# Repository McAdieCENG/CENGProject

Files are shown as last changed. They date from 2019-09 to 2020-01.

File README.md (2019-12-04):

# CENGProject Greenhouse System

## Table of Contents
1. [Introduction](#Introduction)
2. [Bill of Materials](#Bill-of-Materials)
3. [Time Commitment](#Time-Commitment)
4. [Mechanical Assembly](#Mechanical-Assembly)
5. [PCB/Soldering](#PCBSoldering)
6. [Power Up and Unit Testing](#Power-Up-and-Unit-Testing)
7. [Production Testing](#Production-Testing)

## Introduction
Welcome to the build guide for the BME680 sensor to use in devolpment with a greenhouse system. The scope of this project is to learn and integrate a piece of hardware with the broadcomm development platform. In our case, we will be using a Raspberry Pi 3 B+ as our platform to integrate with the BME680 sensor. All of which can then be used for real world applications such as the stated greenhouse system. Below is an image of a finished version of this project.

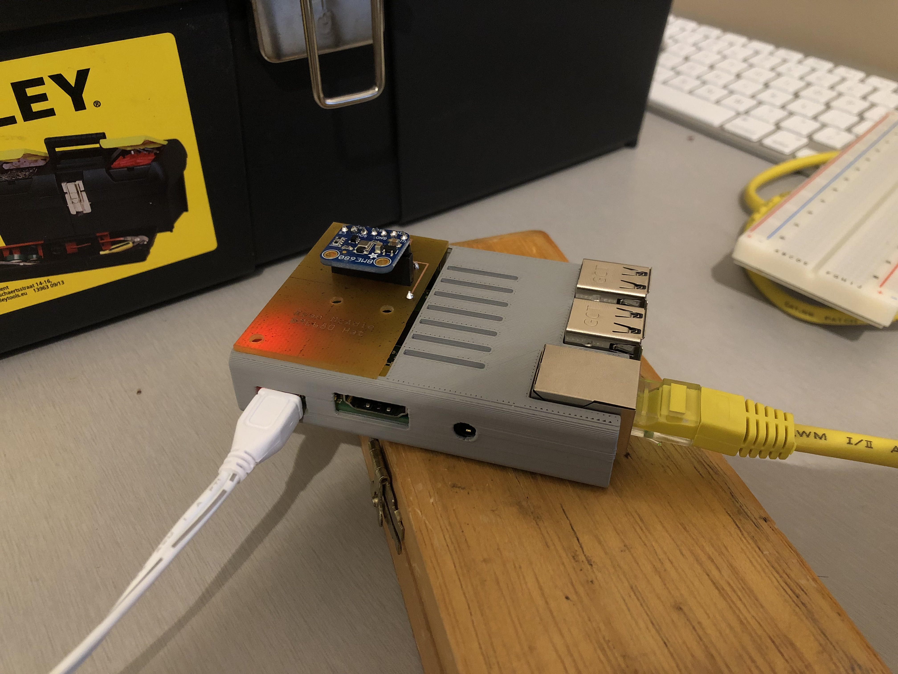
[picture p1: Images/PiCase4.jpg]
Finished Product


## Bill of Materials
**Tools Used:**
- Soldering Iron
- 3D Printer
- PCB Milling Machine
- Wire Cutters/Strippers

**Materials Used:**
- PLA Spool for 3D printer
- PCB Boards
- Small Gage Wire
- Solder

**Other Items Needed/Used**
- Laptop
- Ethernet Cable
- Internet Connection

**Item Budget Sheet: [Click Here for Budget File With Clickable Links](https://github.com/McAdieCENG/CENGProject/blob/master/Documentation/Budget%20Files/Budget.xlsx)**
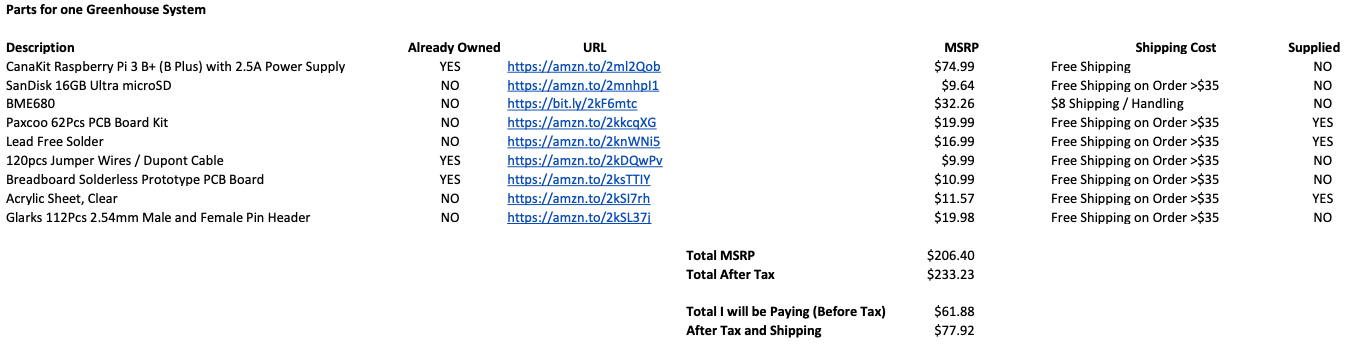
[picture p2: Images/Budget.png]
Budget


These products are what I used to complete this project, some or all products may not be required if you already have access to them or wish to use a supliment product inplace of the ones I have used. **Keep in mind, as a student I was able to aquire my PCB board and 3D printed case for FREE as part of my tuition. These items will need to be aquired by a 3rd party supplier or manufacturer to complete this build and will most likly cost a small fee.**

## Time Commitment
This project ran its course over an entire school semester (4 months, ~15 weeks). The average time per week spend working on this project including class time, was around ~5 hours. With an average understanding of computers and hardware assembly, I would estimate that the time to potentially complete this project would be around 7-8 hours. That being said, I have made this estimate based on the fact that you should have all or most of the required parts at the time of production. Please be advisded of shipping times when ordering parts or materials, some products may be coming from over seas and require longer time to arrive. A full schedule break down for my time used over the school semester can be found [here.](https://github.com/McAdieCENG/CENGProject/blob/master/Documentation/Schedule%20Files/CENG317Schedule-pages-deleted.pdf)

## Mechanical Assembly
**Raspberry Pi Setup:**  
When it comes to setting up your Raspberry Pi for this build there are a few quick tutorials online that can help you through this portion of the build. The first tutorial can be found at this [link here.](https://projects.raspberrypi.org/en/projects/raspberry-pi-setting-up) After completing the initial setup of the Pi following the first link, you can use [this link](https://www.raspberrypi.org/documentation/remote-access/vnc/README.md) to set up the Pi to accept a remote desktop connection through a program called VNC viewer. It may also be a good idea to enable I2C, you can follow this [link here](https://learn.adafruit.com/adafruits-raspberry-pi-lesson-4-gpio-setup/configuring-i2c) to get that done. Lastly, we need to install the appropriate libraries for the BME680 to work properly, just follow [this](https://github.com/adafruit/Adafruit_CircuitPython_BME680) Adafruit GitHub tutorial to get those installed. After completing these few tutorials you can power down your Raspberry Pi for now as we do not need it quite yet.

**Custom Case:**  
If you'd like to 3D print the same case I used in this project the files can be found [here.](https://github.com/McAdieCENG/CENGProject/tree/master/Documentation/Case%20Files) You can either use the program [OpenSCAD](https://www.openscad.org/) to edit the `.scad` file to your liking OR use the file `Case.stl` as is to print the same case I used for the build.

**Breadboard Setup: (This step is optional, can be used to verify the integrity of the sensor)**  
1. Connect wires to the sensor and the development platform like shown below:
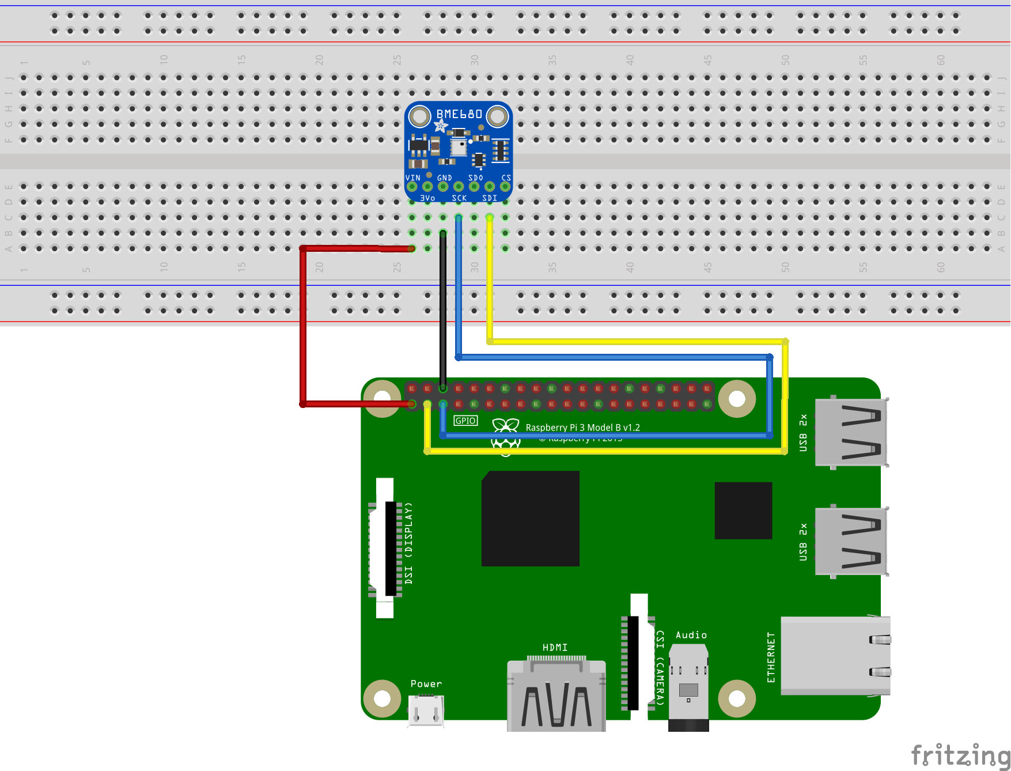
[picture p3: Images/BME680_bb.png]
Breadboard

2. Download the test program from [here](https://github.com/McAdieCENG/CENGProject/tree/master/Software). Transfer this file over to the development platform if you didn't already download it from the development platform.
3. Run the program on the development platform and make sure you are getting readings from your sensor.

## PCB/Soldering
For this part of the project please make sure you proceeded with care and caution. It is advised to double check your designs before purchasing etching and cutting services.

Step 1: Fritzing  
[Fritzing](https://fritzing.org/download/) is an open-source application that allows users to create PCB schematics for different development platforms. It is highly customizable and easy to use.
1. Download and extract Fritzing. Installation notes are on the linked page for various operating systems.
2. Download my Fritzing file [here](https://github.com/McAdieCENG/CENGProject/blob/master/Electronics/BME680%20PCB.fzz) and open it. From the PCB tab, you can make changes at your leisure and pick it apart to see how it was made.  
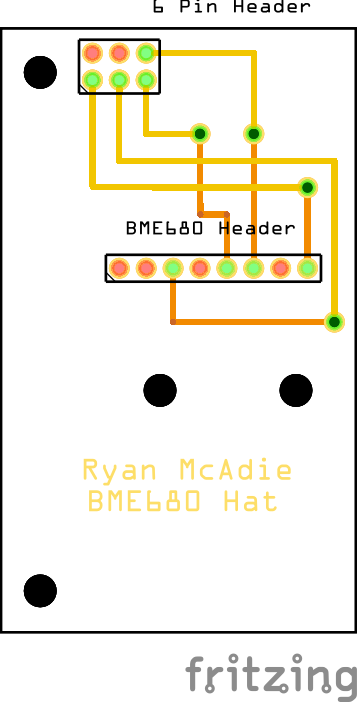
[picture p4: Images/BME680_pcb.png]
PCB
  
3.Export the file as a gerber file. `File > Export for production > Extended Gerber`. Keep track of its save location so you know where to access it next.
4. ZIP/Compress the folder containing the gerber files to send to the etcher of your choice.

Step 2: Soldering  
Once you have you PCB board returned you can start soldering your components. Please note, if you designed your own PCB make sure the connections are correct as a bad connection could result in a short circuit causing damage to your sensor or development platform itself.
1. Start by getting your BME680, the 8 pin connector that came with the BME680, a 6 pin header and an 8 pin header from the headers kit, wire strippers, copper wire, solder, your soldering iron and of course your PCB.
2. Solder the 8 pin connector to the BME680. This can be done by putting the longer end of the 8-pin into your breadboard and place your sensor holes into the upright pins and solder all of the pins. This will ensure your sensor doesn’t move too much during soldering along with givng you the optimal connectivity.
3. Solder your vias on your PCB. The vias are the holes that allow for connections to be made from one side of the board to the other. MY PCB designed board has 4 vias that need to be soldered. The easiest method I found, was to strip your copper wiring, stick it into the breadboard, and slide one via onto it so that it is flat and stable for soldering.
4. Now it is time to solder your headers to the board. We will start with the 6 pin, like the image below we want the header to be soldered to the bottom of the board so it can be plugged into the GPIO pins on the Raspberry Pi.  
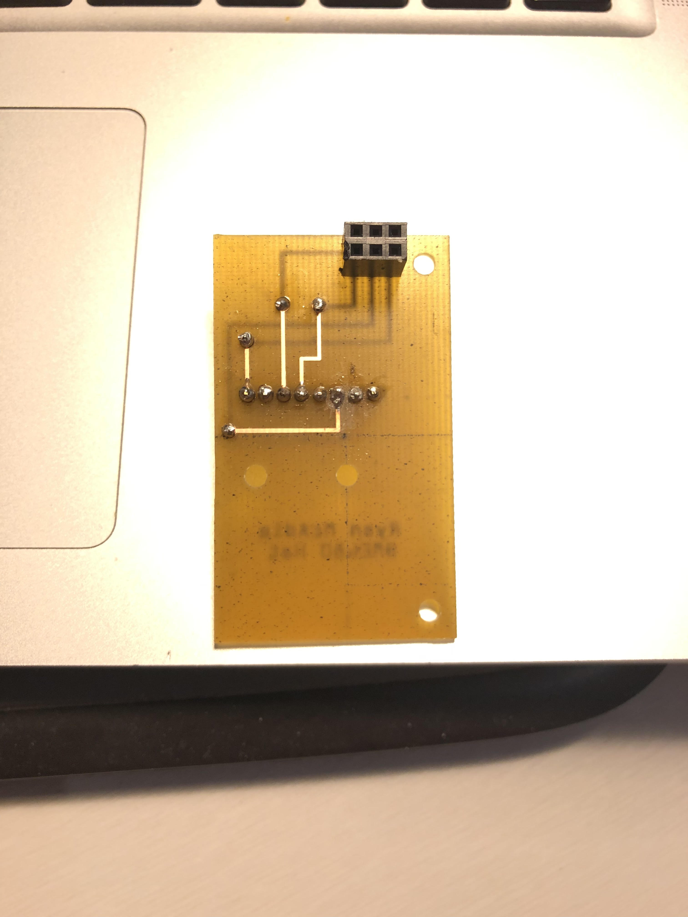
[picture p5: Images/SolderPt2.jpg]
6Pin

5.Do the same you did for the 6 pin header now for the 8 pin header, except make sure you flip the board over so the 8 pin header is soldered to the top of the board. Refrence the image below.  
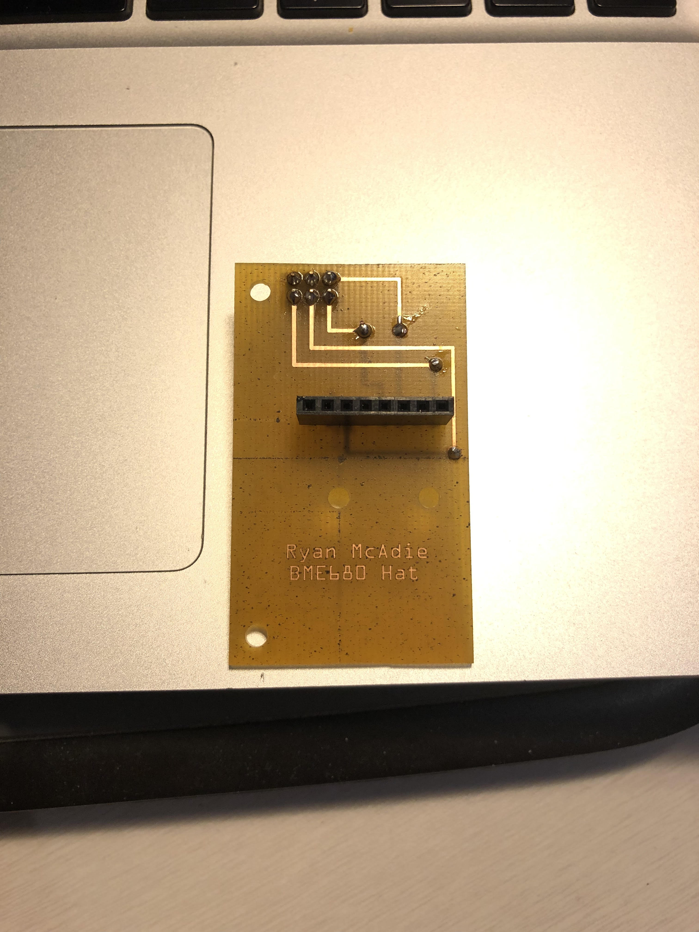
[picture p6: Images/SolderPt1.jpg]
8Pin

6. You should now be able to plug your sensor into the 8 pin header on the board. Make sure you line up the holes on the sensor with the cut holes on the board so the proper pins are being used to power the sensor and grab data from it as well. Refrence the below image.  
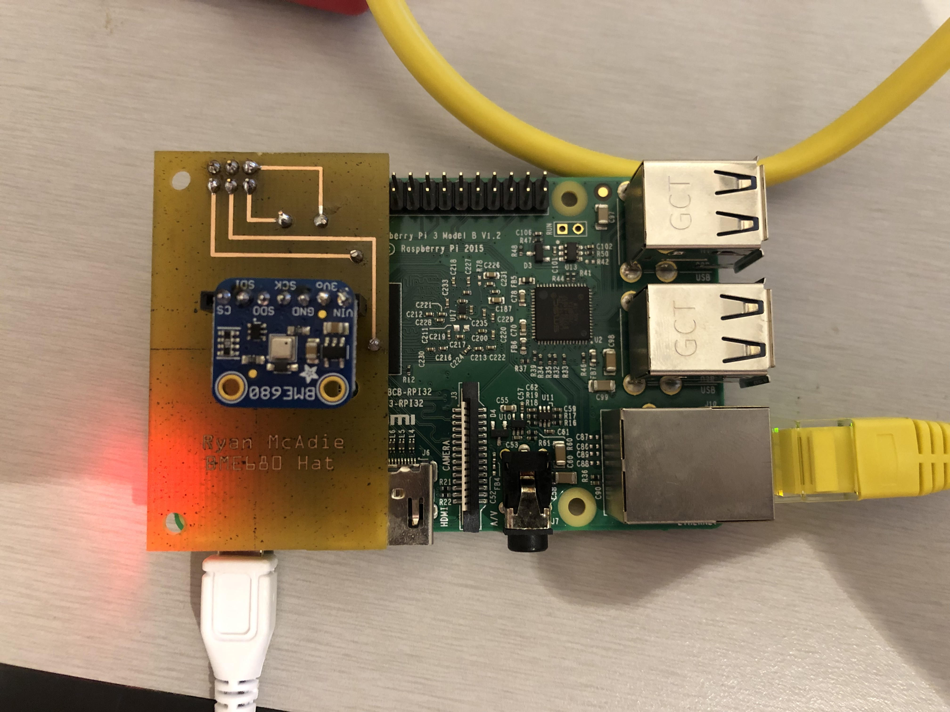
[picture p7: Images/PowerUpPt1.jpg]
FinishedBoard


## Power Up and Unit Testing
Once everything is plugged in, and you have double checked your connections, plug the 6 pin header into the first 6 GPIO pins on the Raspberry Pi and power it on. You can now either download the test program [here](https://github.com/McAdieCENG/CENGProject/tree/master/Software) to see if everything is working properly OR if you have already downloaded it from the breadboard step just re-run the program and make sure you are still able to get readings from the sensor.  
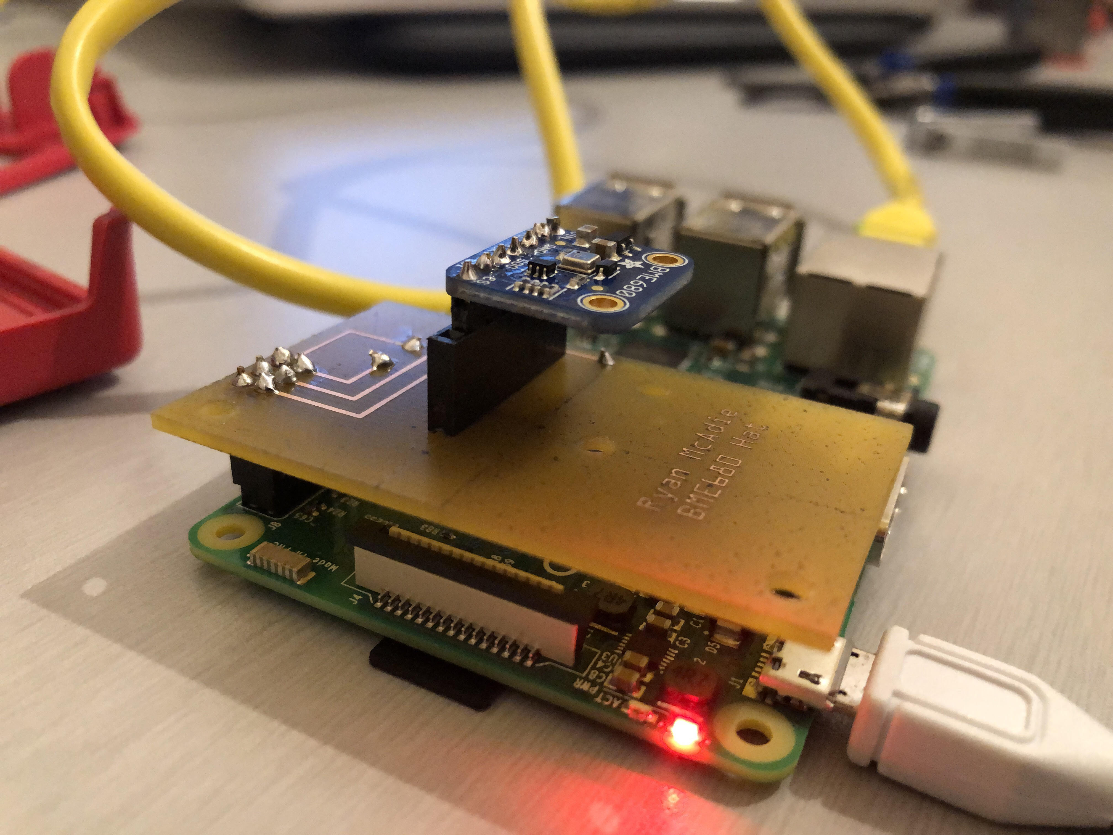
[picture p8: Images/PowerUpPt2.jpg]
PowerUp

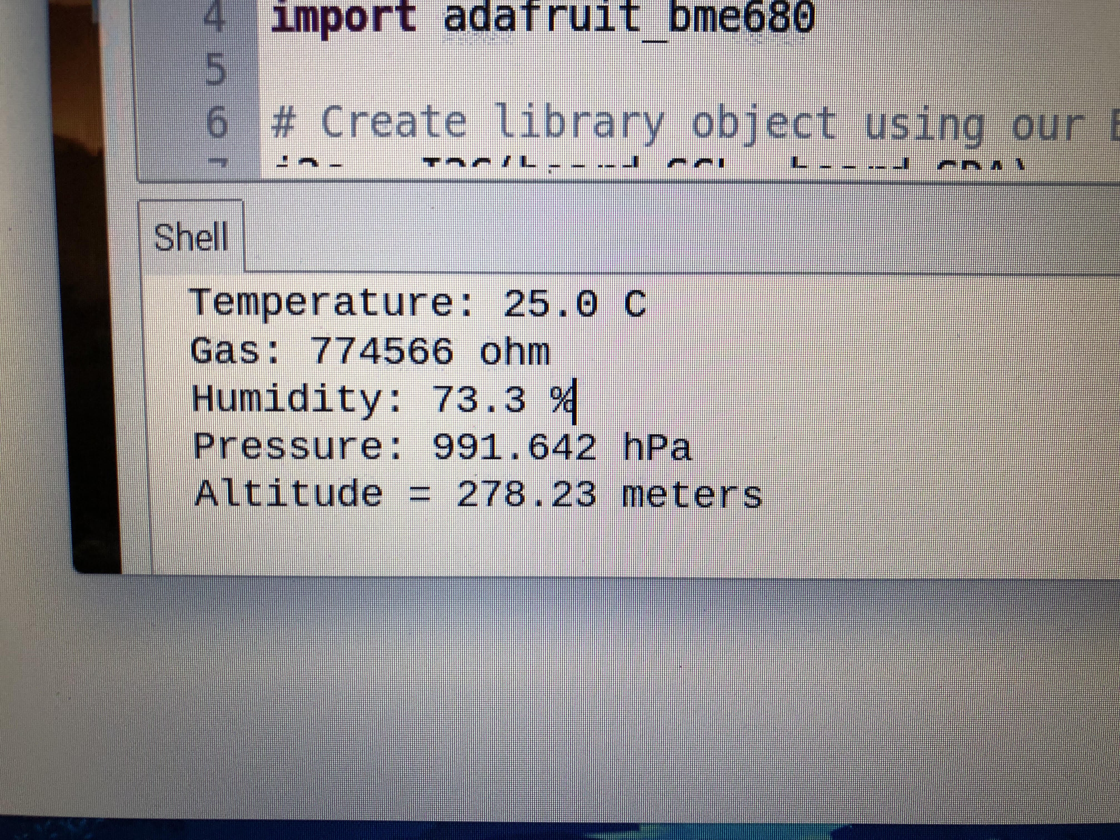
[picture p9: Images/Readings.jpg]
Readings


## Production Testing
For the case of production testing of this board, my suggestion would be to have a fully setup development platform for easy access to the test software and libraries for once the PCB's have been soldered and are ready for testing. As for testing you'd just have to connect a BME680 sensor to the 8 pin header on the board and run the test program, if you can display readings from the sensor then the board is functional and ready to distribute.  
  
This concludes the end of the build instructions, I hope you had as much fun with this project as I did!

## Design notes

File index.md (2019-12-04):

# Greenhouse System Project Blog Updates

### December 3, 2019
Today was my day to present my project to the class. The presentation went smothly and the demo of the project went according to plan. No issues aroused during the presentation or demo time.  
I also have finsihed my build instructions in the "README.md" file concluding my work for this course.

### November 26, 2019
Uploaded my project presentation to the [presentations](https://github.com/McAdieCENG/CENGProject/tree/master/Documentation/Presentations) folder in the documents tab. I will be presenting this to the class next week on December 3rd, 2019

### November 25, 2019
Today I was able to pick up my 3D printed case from Humbers Prototype Lab. Here are the images of the case with the development platform enclosed.
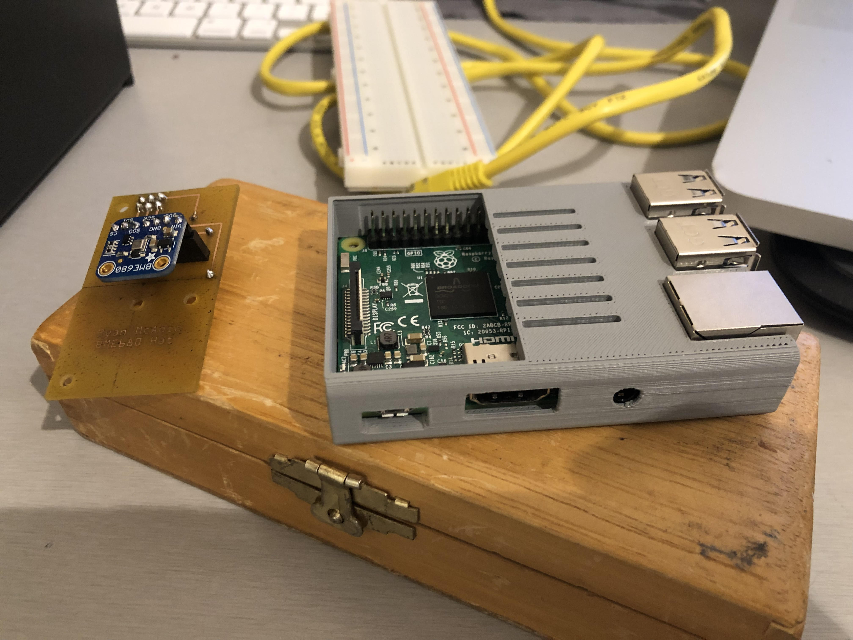
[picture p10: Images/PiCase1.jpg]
PiCase1

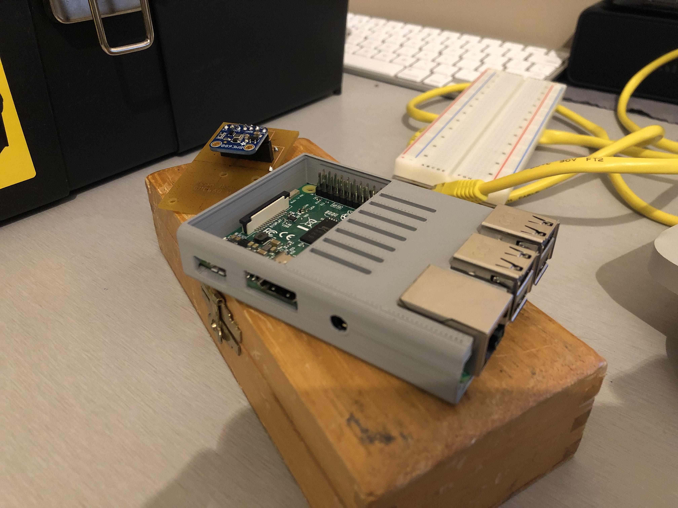
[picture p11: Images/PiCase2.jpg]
PiCase2

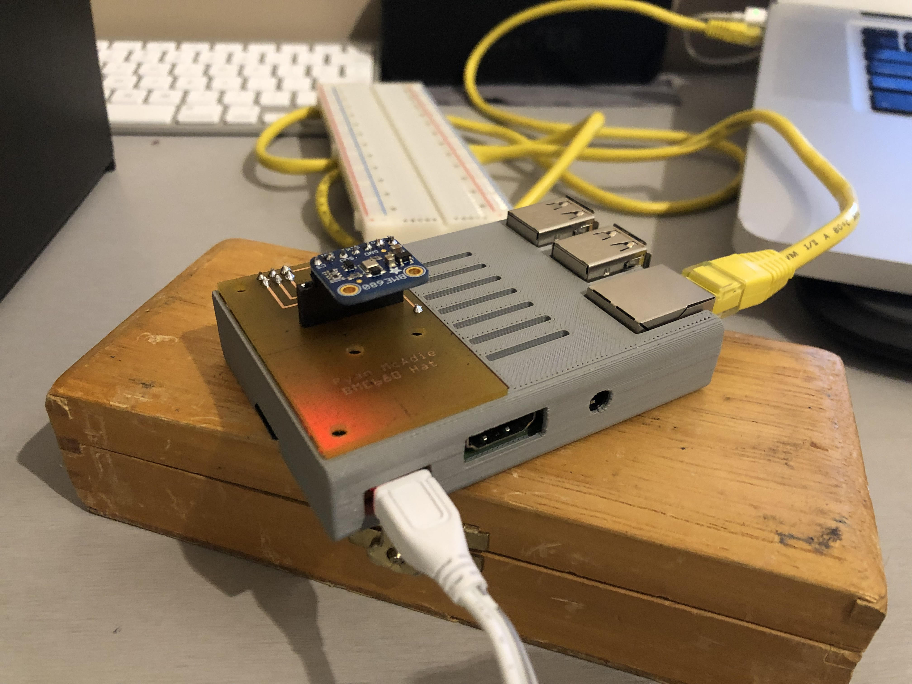
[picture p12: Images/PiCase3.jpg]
PiCase3

PiCase4

### November 19, 2019
This is the week that the enclosure is due unfortunately, I was unable to have my enclosure present with me in class today. It has been completed but the person I had print the case for me forget to bring it with them to give to me. The appropriate files have been uploaded to the [Case Files](https://github.com/McAdieCENG/CENGProject/tree/master/Documentation/Case%20Files) folder on my repository. My case is a modified version of the case found [here](https://www.thingiverse.com/thing:604915). Since I do not have my case to take pictures of I have uploaded the images of what the case currently looks like and will upload the real case once it is in my possession.
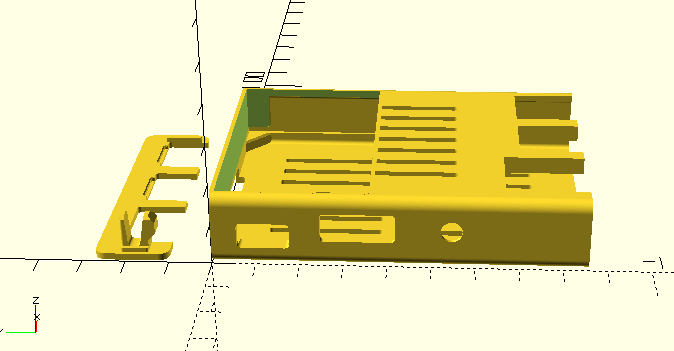
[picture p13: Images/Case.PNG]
Case


### November 12, 2019
Updates for this past week have been posted below. I am still on track with my purposed schedule and project plan for this semester, as well, I am still on with regards to my budget and have not had any unexpected increases to my budget.
- Uploaded Progress report to GitHub [documentation folder](https://github.com/McAdieCENG/CENGProject/tree/master/Documentation/Progress%20Updates)
- PCB powered up and able to display readings from sensor
PowerUpPt1
PowerUpPt2
Readings
- Started and finsihing up enclosure design to have ready for next weeks class

### November 5, 2019
Finished with soldering my PCB with all my components, and have uploaded the pictures to the [images folder](https://github.com/McAdieCENG/CENGProject/tree/master/Images). Currently, as far as my budget, project plan, purposal and schedule I am on track with completing my project without having to make changes to my budget or my project plan. At this point in time, I have assembled and completed all required steps and process to have my project ready for PCB power up next week. I will continue to test my development platform connection with my sensor to make sure everything is working like it should. Below are pictures of my finsihed PCB.
SolderPt1
SolderPt2

### October 29, 2019
Currently, I am on track with my project in terms of the actual work as well as finacially, meaning that I have had no unexpected fees or costs up to this point in time.
- Demonstrated a working breadboard of the project to the Professor
- Changed the wire colours inside the fritzing file to match the wires I used today to complete the breadboard
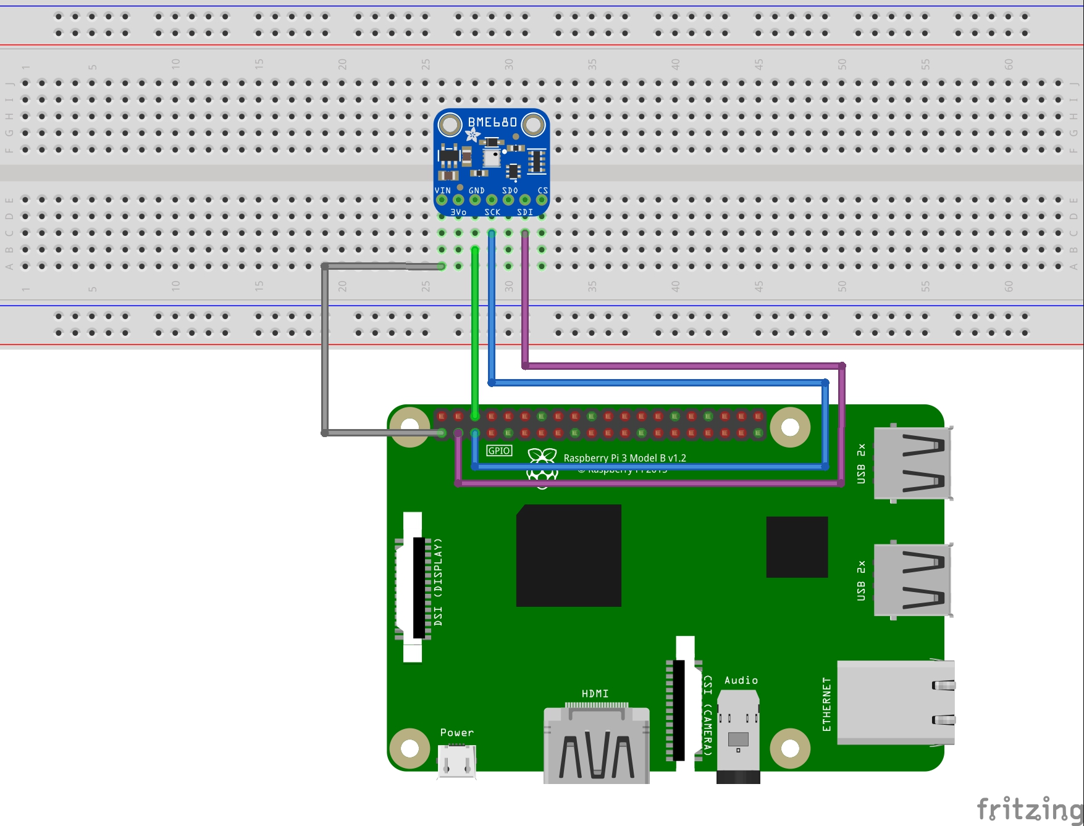
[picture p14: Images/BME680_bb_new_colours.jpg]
Colour Change for Wires New Wire Colours

- Uploaded the image of the [working breadboard](https://github.com/McAdieCENG/CENGProject/tree/master/Images)
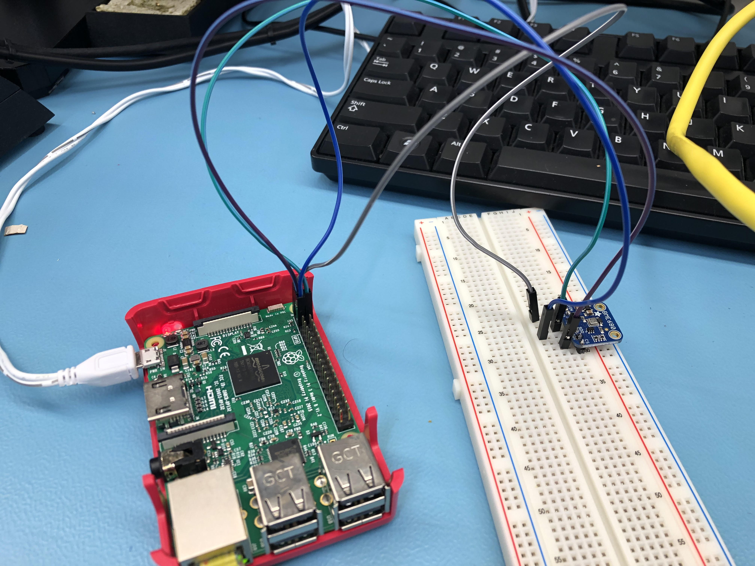
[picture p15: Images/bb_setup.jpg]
Working Breadboard

- Uploaded sample code used to demo the BME680 wokring correctly into the [software folder](https://github.com/McAdieCENG/CENGProject/tree/master/Software)

### October 22, 2019
Currently, we are in reading week for this semester so to stay on track with the project I used this time to load my development platform with an OS and made sure everything was working and up to date for when I return to class next week. Installation also included the downloading and installation of the correct librarys to use the BME680 with the development platform  

### October 15, 2019
- Finished up Breadboard, Schematic and PCB views for my BME680 Hat that will attach to a Raspberry Pi 3 B+. Images uploaded here: [BME680 Images](https://github.com/McAdieCENG/CENGProject/tree/master/Images) 
BME680_BB
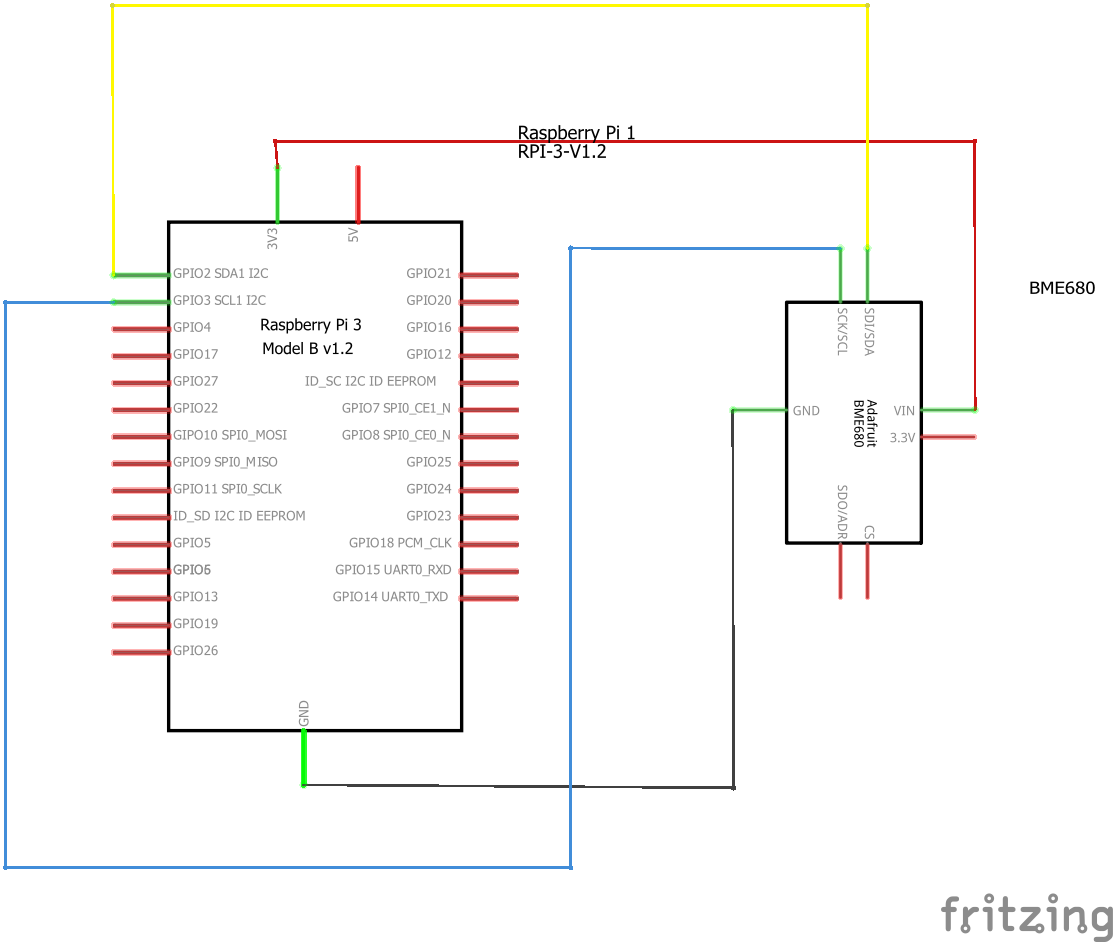
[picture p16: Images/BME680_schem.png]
BME680_Schem

BME680_PCB
- Sent PCB Gerber files to Humber Prototype Lab for fabrication. Gerber files uploaded here: [BME680 Gerber Files](https://github.com/McAdieCENG/CENGProject/tree/master/Electronics)
- Uploaded both Fritzing Files used, one with a Raspberry Pi and one without. Uploaded files here: [BME680 Fritzing Files](https://github.com/McAdieCENG/CENGProject/tree/master/Electronics)

### October 8, 2019
Showed what I purchased for my project that I didn't already own. As well as, went over safety procedures and safty drills during the lab time and watched videos on soldering.

### October 1, 2019
- Fixed up budget files to include missing information
- Uploaded Snapshots of recipts for items purchased. [Proof of Purchases](https://github.com/McAdieCENG/CENGProject/tree/master/Images)
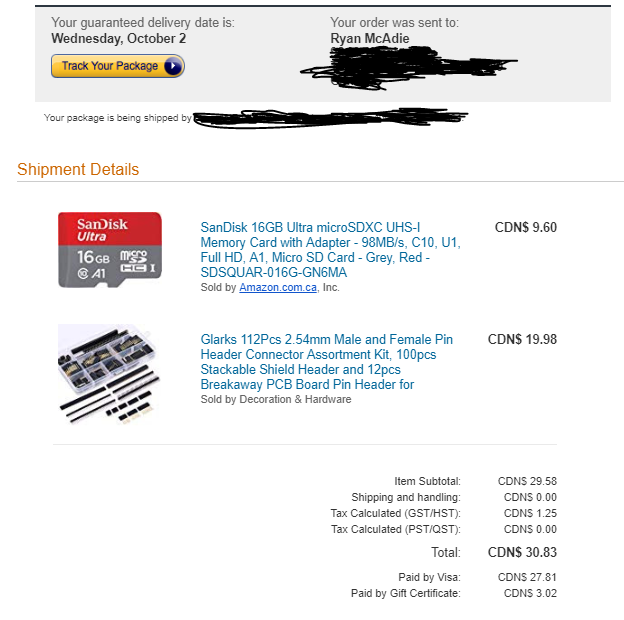
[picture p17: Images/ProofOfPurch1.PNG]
Purchase #1

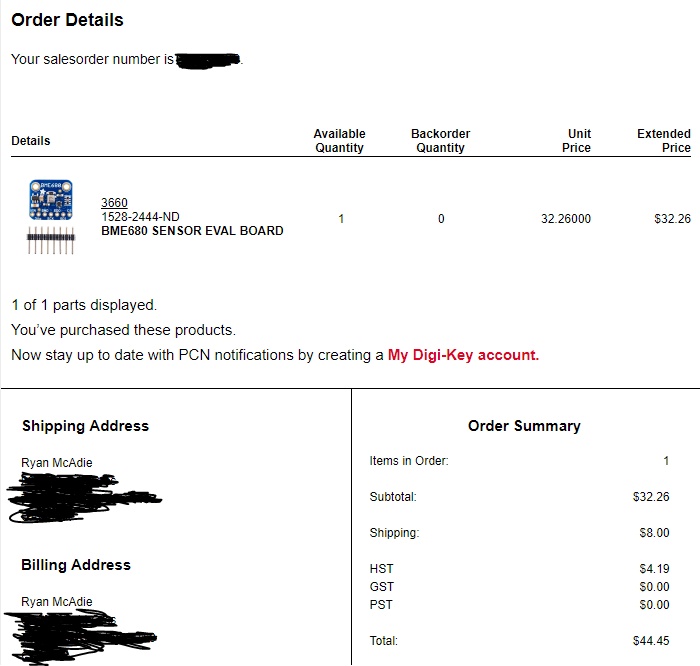
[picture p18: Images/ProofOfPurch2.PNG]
Purchase #2


### September 18, 2019
Uploaded [Budget Files!](https://github.com/McAdieCENG/CENGProject/tree/master/Documentation/Budget%20Files)

### September 17, 2019
Meet with the sponsor of the project Valeria from the Humber Greenhouse. Discussed important features that would benefit her and all different kinds of plants.

### September 12, 2019
Uploaded [Scheduling Files!](https://github.com/McAdieCENG/CENGProject/tree/master/Documentation/Schedule%20Files)

### September 8, 2019
Uploaded [Proposal Files!](https://github.com/McAdieCENG/CENGProject/tree/master/Documentation/Proposal%20Files)

### September 3, 2019
- Repository Created!
- Group Members Picked!
- Project Selected

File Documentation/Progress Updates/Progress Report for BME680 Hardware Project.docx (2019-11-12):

Progress Report for BME680 Hardware Project

CENG-317-0NB

Ryan McAdie (N01158072)

November 12, 2019

This progress report serves the purpose to discuss the current work situation with my BME680 hardware project that will be later implemented into a larger project in the coming semester. Currently, the project is on track with the purposed schedule made at the beginning of the term. All predecessor tasks have been completed allowing the project to continue on a steady pace which will allow it to finish on time and in working order. As of now the project has not ran into any significate or time delaying obstacles such as unplanned for situations regarding a broken sensor or malfunctioning development platform, along with unforeseen wait times to receive a finished PCB or ordered parts. This has allowed me to continuously work and move forward at a comfortable pace with the project. The same goes for the financial end of the project as well. I have operated inside the purposed budget for the project and have not yet occurred any other costs or finical deficits that could raise the currently set budget of the project. I believe that if everything continues to move at the current pace, I will be well prepared for the end of term with a working sensor connected to a development platform inside a custom case designed to house all parts and equipment accordingly. To stay up to date on a week to week basis the project has its own GitHub blog that can be found at; https://mcadieceng.github.io/CENGProject/. This blog provides more in-depth information about the project and where it stands every week, and will be continuously updated with information regarding the project until it is completed.

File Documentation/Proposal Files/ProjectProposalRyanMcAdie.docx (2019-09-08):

2019-09-10

Proposal for the development of Greenhouse System Scale Model

Prepared by Ryan McAdie, Daniel Bujold, and Aiden Waadallah
Computer Engineering Technology Students
https://github.com/McAdieCENG/CENGProject

Executive Summary

The database will store Temperature, Humidity, Soil Moisture Levels. The mobile device functionality will include The mobile application will display temp, humidity and soil moisture levels when the user logs in. They will also be given the option to access a camera to take a picture to post on social media. I will be collaborating with the following company/department I will be collaborating with Humber Arboretum. In the winter semester I plan to form a group with the following students, who are also building similar hardware this term and working on the mobile application with me Myself (Ryan McAdie), Daniel Bujold. The hardware will be completed in CENG 317 Hardware Production Techniques independently and the application will be completed in CENG 319 Software Project. These will be integrated together in the subsequent term in CENG 355 Computer Systems Project as a member of a 2 or 3 student group.

Background

The problem solved by this project is The real life problem being solved by this project is that Humber arboretum and several other nurseries don’t have a proper system to measure temperature, humidity and soil moisture levels. This monitoring system will help them to keep track of everything related to the health if the habitat.. A bit of background about this topic is Humber Arboretum needs a system to measure and display, in real-time, the appearance, temperature, humidity, and soil moisture of the plants in its nursery. Through an app, employees can view these measurements online. It will be connected to the firebase database through the internet. Firebase server will hold all the levels measured by the sensors and will send it to the mobile application. The mobile application will display those levels on the screen when the user's login. There is an additional camera option in the app which will allow users to click the picture and share it on social media..

Existing products on the market include “Sensaphone Remote Monitoring Solutions Greenhouse Remote Monitoring Systems”, “Climate Control Systems Greenhouse Sensor Systems” and “Monnit Remote Monitoring Systems for Greenhouse Monitoring”.

In the Computer Engineering Technology program, we have learned about the following topics from the respective relevant courses:

- Java Docs from CENG 212 Programming Techniques In Java,
- Construction of circuits from CENG 215 Digital And Interfacing Systems,
- Rapid application development and Gantt charts from CENG 216 Intro to Software Engineering,
- Micro computing from CENG 252 Embedded Systems,
- SQL from CENG 254 Database With Java,
- Web access of databases from CENG 256 Internet Scripting; and,
- Wireless protocols such as 802.11 from TECH152 Telecom Networks.

This knowledge and skill set will enable me to build the subsystems and integrate them together as my capstone project.

Methodology

This proposal is assigned in the first week of class and is due at the beginning of class in the second week of the fall semester. My coursework will focus on the first two of the 3 phases of this project:
Phase 1 Hardware build.
Phase 2 System integration.
Phase 3 Demonstration to future employers.

Phase 1 Hardware build

The hardware build will be completed in the fall term. It will fit within the CENG Project maximum dimensions of 12 13/16" x 6" x 2 7/8" (32.5cm x 15.25cm x 7.25cm) which represents the space below the tray in the parts kit. The highest AC voltage that will be used is 16Vrms from a wall adaptor from which +/- 15V or as high as 45 VDC can be obtained. Maximum power consumption will be 20 Watts.

Phase 2 System integration

The system integration will be completed in the fall term.

Phase 3 Demonstration to future employers

This project will showcase the knowledge and skills that I have learned to potential employers.

The brief description below provides rough effort and non-labor estimates respectively for each phase. A Gantt chart will be added by week 3 to provide more project schedule details and a more complete budget will be added by week 4. It is important to start tasks as soon as possible to be able to meet deadlines.

A Raspberry Pi, a BME280 sensor, an EK1940 sensor and possibly a camera that we can hook up to the RPi to take remote photos

Concluding remarks

This proposal presents a plan for providing an IoT solution for To build a device capable of reading temperature, humidity and soil moisture to be used in plant nurseries. Along with a constructed mobile application that can be used to access a database to show users real-time information regarding temp, humidity and soil moisture. This is an opportunity to integrate the knowledge and skills developed in our program to create a collaborative IoT capstone project demonstrating my ability to learn how to support projects such as the initiative described by Humber Arboretum. I request approval of this project.

References

[1] (n.d.). Monnit Remote Monitoring Systems for Greenhouse Monitoring. Retrieved from https://www.monnit.com/solutions/greenhouse-monitoring Labbate, E. (2018, March 19). Greenhouse Sensor Systems for Real Time Monitoring and Control Greenhouse Automation Systems. Retrieved from https://www.climatecontrol.com/blog/greenhouse-sensor-systems/

[2] Institute of Electrical and Electronics Engineers. (2015, August 28). IEEE Xplore Digital Library [Online]. Available: https://ieeexplore.ieee.org/search/advsearch.jsp

[3] An IoT-Based Traceability System for Greenhouse Seedling Crops G. Ramirez-González (2018). . IEEE Access, 6, 67528-67535. https://ieeexplore.ieee.org/document/8502066

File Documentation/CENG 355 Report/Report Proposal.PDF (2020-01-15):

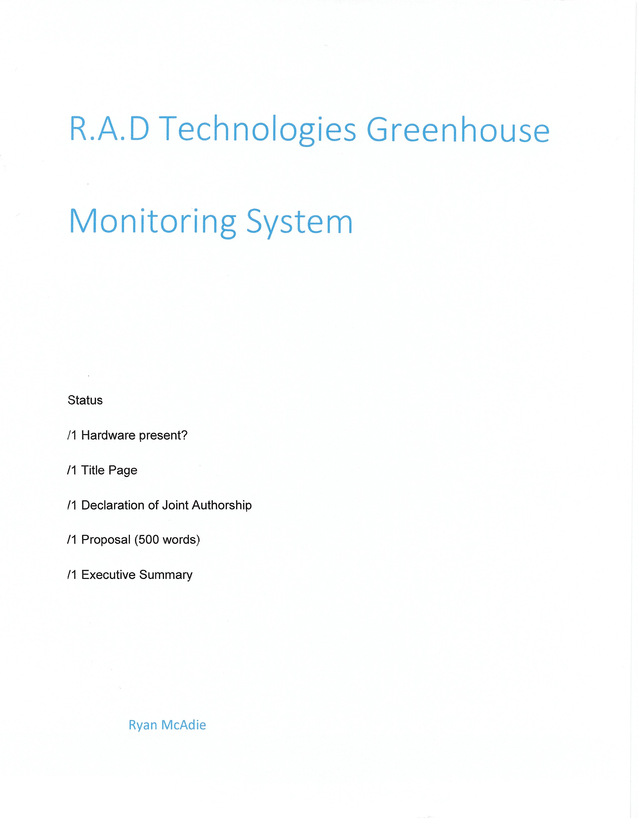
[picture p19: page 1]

Declaration of Joint Authorship

We, Ryan McAdie, Daniel Bujold, and Aiden Bolos, confirm that this work submitted is

the joint work of our group and is expressed our own words. Any uses made within it of

the works of any other author, in any form (ideas, equations, figures, texts, tables,

programs), are properly acknowledged at the point of use. A list of the references used

is included. The work breakdown is as follows: Each of us provided functioning,

documented hardware for a sensor or effector. Ryan McAdie provided documentation

for the BME680 Gas and Air Quality Sensor. Daniel Bujold provided documentation for

the Capacitive Moisture Sensor. Aiden Bolos provided documentation for the DS18B20

Temperature Sensor. In the integration effort Ryan McAdie is the lead for further

development of our mobile application, Daniel Bujold is the lead for the Hardware, and

Aiden Bolos is the lead for connecting the two via the Database.

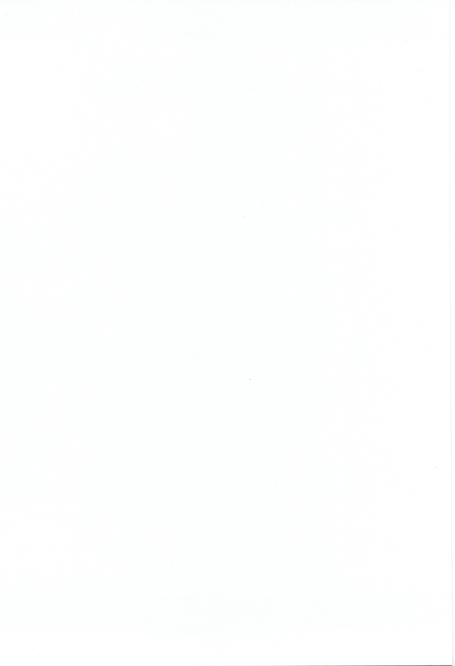
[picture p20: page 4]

### Proposal

We hav created a mobile application, worked with databases, completed a software

engineering course, and prototyped a small embedded system with a custom PCB as

well as an enclosure (3D printed/laser cut). Our Internet of Things (loT) capstone project

uses a distributed computing model of a smart phone application, a database

accessible via the internet, an enterprise wireless (capable of storing certificates)

connected embedded system prototype with a custom PCB as well as an enclosure (3D

printed/laser cut), and are documented via this technical report targeting OACETT

certification guidelines.

Intended project key component descriptions and part numbers

Development platform: Raspberry Pi (Broadcom Development Platform)

Sensor/Effector 1: BME680

Sensor/Effector 2: Capacitive Moisture Sensor EK1940

Sensor/Effector 3: DS18820 Temperature Sensor

We will continue to develop skills to configure operating systems, networks, and

embedded systems using these key components to complete a small-scale system of a

greenhouse monitoring system that will be capable of accurately retrieving and

displaying real time up to date vital information for the greenhouse environment.

Systems like this currently exist in the world today, however looking at Humber's current

system we noticed that all changes can only be made from a central computer located

in the greenhouse, we would like to incorporate a remote monitoring and allow remote

changes to our system for convivence and to always know how the greenhouse is doing. We also plan to incorporate systems that can be accessed remotely from inside

the greenhouse using our related mobile application. Such systems we currently have in

mind are; an irrigation system that can automatically or manually water the plants as

needed, a ventilation system that can be accessed to regulate temperatures inside the

greenhouse and a blind system that can be used to block intense light and heat from

the sun if needed for the plants.

Our project description/specifications will be reviewed by, Valeria an employee of the

Humber Greenhouse, ideally an employer in a position to potentially hire once we

graduate. They will also ideally attend the ICT Capstone Expo to see the outcome and

be eligible to apply for NSERC funded extension projects. This typically means that they

are from a Canadian company that has been revenue generating for a minimum of two

years and have a minimum of two full time employees.

The small physical prototypes that we build are to be small and safe enough to be

brought to class every week as well as be worked on at home. In alignment with the

space below the tray in the Humber North Campus Electronics Parts kit the overall

project maximum dimensions are 12 13/16" x 6" x 2 7/8" = 32.5cm x 15.25cm x 7.25cm.

Keeping safety and Z462 in mind, the highest AC voltage that will be used is 16Vrms

from a wall adapter from which+/- 15V or as high as 45 VDC can be obtained.

Maximum power consumption will not exceed 20 Watts. We are working with prototypes

and that prototypes are not to be left powered unattended despite the connectivity that

we develop.

Executive Summary

With our greenhouse system users will be able to monitor real time vital information to

their greenhouses such as temperature, humidity and soil moisture. These values will

be updated in real time so users will always know the state of the greenhouse and if

changes need to be made. We are also going to implement a remote management

system for certain features of the greenhouse such as an irrigation/feeding system,

ventilation and fan system and a light blocking or blind system. With all these, a user

would be able to take manual control of the greenhouse and make remote changes to

the system that could potentially be better for the plants then just using the automated

system. Our system will be one of the first of its kind to implement all the necessary

features of a greenhouse monitoring system as well as go above and beyond to achieve

features and requirements that would make managing a greenhouse a little more easier

with more peace of mind knowing that your plants are always in your hands.

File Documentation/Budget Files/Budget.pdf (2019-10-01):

Parts for one Greenhouse System

Description | Already Owned | URL | MSRP | Shipping Cost | Supplied
CanaKit Raspberry Pi 3 B+ (B Plus) with 2.5A Power Supply | YES | https://amzn.to/2ml2Qob | $74.99 | Free Shipping | NO
SanDisk 16GB Ultra microSD | NO | https://amzn.to/2mnhpI1 | $9.64 | Free Shipping on Order >$35 | NO
BME680 | NO | https://bit.ly/2kF6mtc | $32.26 | $8 Shipping / Handling | NO
Paxcoo 62Pcs PCB Board Kit | NO | https://amzn.to/2kkcqXG | $19.99 | Free Shipping on Order >$35 | YES
Lead Free Solder | NO | https://amzn.to/2knWNi5 | $16.99 | Free Shipping on Order >$35 | YES
120pcs Jumper Wires / Dupont Cable | YES | https://amzn.to/2kDQwPv | $9.99 | Free Shipping on Order >$35 | NO
Breadboard Solderless Prototype PCB Board | YES | https://amzn.to/2ksTTIY | $10.99 | Free Shipping on Order >$35 | NO
Acrylic Sheet, Clear | NO | https://amzn.to/2kSI7rh | $11.57 | Free Shipping on Order >$35 | YES
Glarks 112Pcs 2.54mm Male and Female Pin Header | NO | https://amzn.to/2kSL37j | $19.98 | Free Shipping on Order >$35 | NO
Total MSRP | $206.40
Total After Tax | $233.23
Total I will be Paying (Before Tax) | $61.88
After Tax and Shipping | $77.92

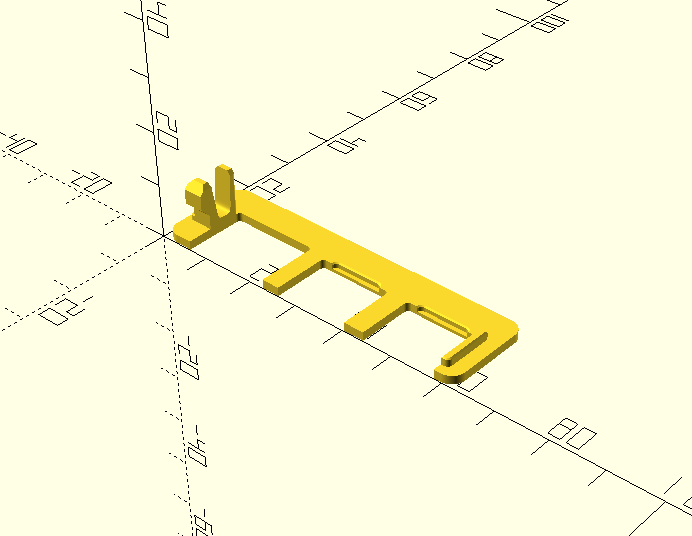
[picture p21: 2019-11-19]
Images/CAP.PNG

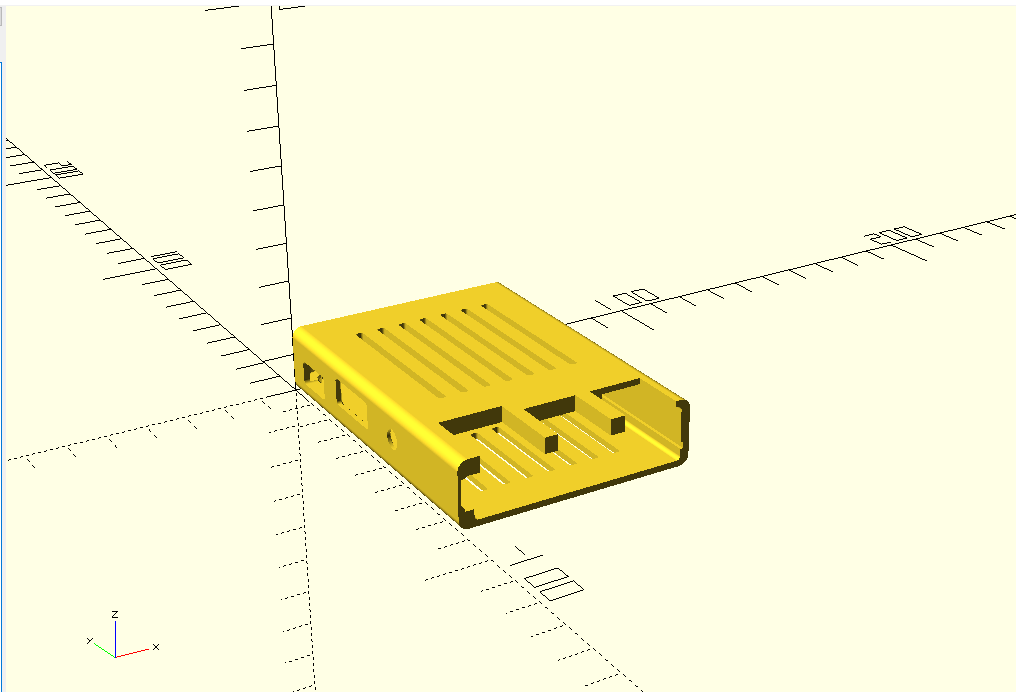
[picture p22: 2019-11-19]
Images/MAIN_BODY.PNG

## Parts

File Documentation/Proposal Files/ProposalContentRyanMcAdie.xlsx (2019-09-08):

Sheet: DataEntry
Submission Date | 2019-09-10
Project Name | Greenhouse System Scale Model
Student Names | Ryan McAdie, Daniel Bujold, and Aiden Waadallah
Project repository | https://github.com/McAdieCENG/CENGProject
Sensors Effectors choices | BME280 For Temp and Humidity, EK1940 Soil Moisture Sensor
The database will store | Temperature, Humidity, Soil Moisture Levels
The mobile device functionality will include | The mobile application will display temp, humidity and soil moisture levels when the user logs in. They will also be given the option to access a camera to take a picture to post on social media
I will be collaborating with the following company/department | I will be collaborating with Humber Arboretum
My group in the winter semester will include | Myself (Ryan McAdie), Daniel Bujold
50 word problem statement | The real life problem being solved by this project is that Humber arboretum and several other nurseries don’t have a proper system to measure temperature, humidity and soil moisture levels. This monitoring system will help them to keep track of everything related to the health if the habitat.
100 words of background | Humber Arboretum needs a system to measure and display, in real-time, the appearance, temperature, humidity, and soil moisture of the plants in its nursery. Through an app, employees can view these measurements online. It will be connected to the firebase database through the internet. Firebase server will hold all the levels measured by the sensors and will send it to the mobile application. The mobile application will display those levels on the screen when the user's login. There is an additional camera option in the app which will allow users to click the picture and share it on social media.
Current product APA citation | (n.d.). Monnit Remote Monitoring Systems for Greenhouse Monitoring. Retrieved from https://www.monnit.com/solutions/greenhouse-monitoring Labbate, E. (2018, March 19). Greenhouse Sensor Systems for Real Time Monitoring and Control Greenhouse Automation Systems. Retrieved from https://www.climatecontrol.com/blog/greenhouse-sensor-systems/
Existing research IEEE paper APA citation | An IoT-Based Traceability System for Greenhouse Seedling Crops G. Ramirez-González (2018). . IEEE Access, 6, 67528-67535. https://ieeexplore.ieee.org/document/8502066
Brief description of planned purchases | A Raspberry Pi, a BME280 sensor, an EK1940 sensor and possibly a camera that we can hook up to the RPi to take remote photos
Solution description | To build a device capable of reading temperature, humidity and soil moisture to be used in plant nurseries. Along with a constructed mobile application that can be used to access a database to show users real-time information regarding temp, humidity and soil moisture

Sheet: DataBase
Submission Date | Project Name | Student Names | Project repository | Sensors Effectors choices | The database will store | The mobile device functionality will include | I will be collaborating with the following company/department | My group in the winter semester will include | 50 word problem statement | 100 words of background | Current product APA citation | Existing research IEEE paper APA citation | Brief description of planned purchases | Solution description
43718 | Greenhouse System Scale Model | Ryan McAdie, Daniel Bujold, and Aiden Waadallah | https://github.com/McAdieCENG/CENGProject | BME280 For Temp and Humidity, EK1940 Soil Moisture Sensor | Temperature, Humidity, Soil Moisture Levels | The mobile application will display temp, humidity and soil moisture levels when the user logs in. They will also be given the option to access a camera to take a picture to post on social media | I will be collaborating with Humber Arboretum | Myself (Ryan McAdie), Daniel Bujold | The real life problem being solved by this project is that Humber arboretum and several other nurseries don’t have a proper system to measure temperature, humidity and soil moisture levels. This monitoring system will help them to keep track of everything related to the health if the habitat. | Humber Arboretum needs a system to measure and display, in real-time, the appearance, temperature, humidity, and soil moisture of the plants in its nursery. Through an app, employees can view these measurements online. It will be connected to the firebase database through the internet. Firebase server will hold all the levels measured by the sensors and will send it to the mobile application. The mobile application will display those levels on the screen when the user's login. There is an additional camera option in the app which will allow users to click the picture and share it on social media. | (n.d.). Monnit Remote Monitoring Systems for Greenhouse Monitoring. Retrieved from https://www.monnit.com/solutions/greenhouse-monitoring Labbate, E. (2018, March 19). Greenhouse Sensor Systems for Real Time Monitoring and Control Greenhouse Automation Systems. Retrieved from https://www.climatecontrol.com/blog/greenhouse-sensor-systems/ | An IoT-Based Traceability System for Greenhouse Seedling Crops G. Ramirez-González (2018). . IEEE Access, 6, 67528-67535. https://ieeexplore.ieee.org/document/8502066 | A Raspberry Pi, a BME280 sensor, an EK1940 sensor and possibly a camera that we can hook up to the RPi to take remote photos | To build a device capable of reading temperature, humidity and soil moisture to be used in plant nurseries. Along with a constructed mobile application that can be used to access a database to show users real-time information regarding temp, humidity and soil moisture

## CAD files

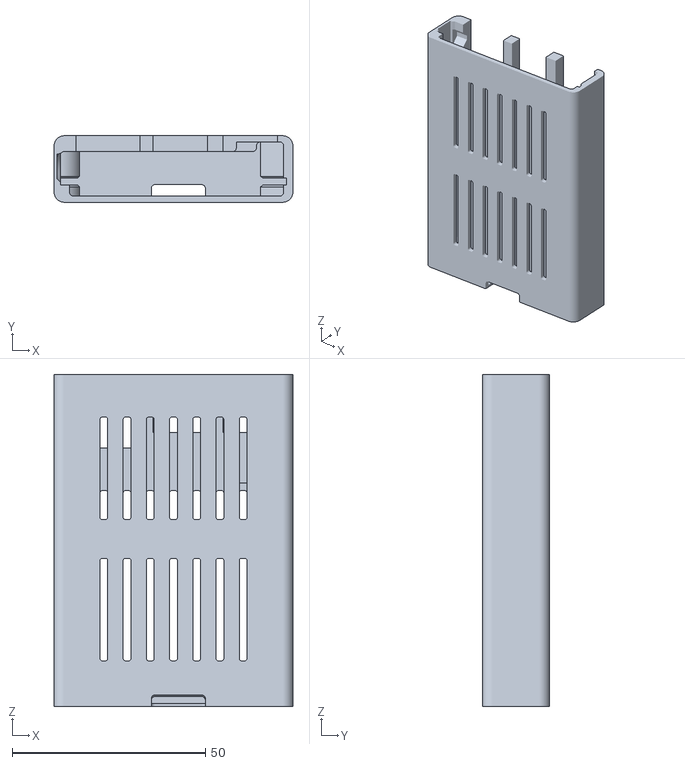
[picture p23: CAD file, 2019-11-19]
Documentation/Case Files/MAIN.STL
61.7 x 17.2 x 85.8

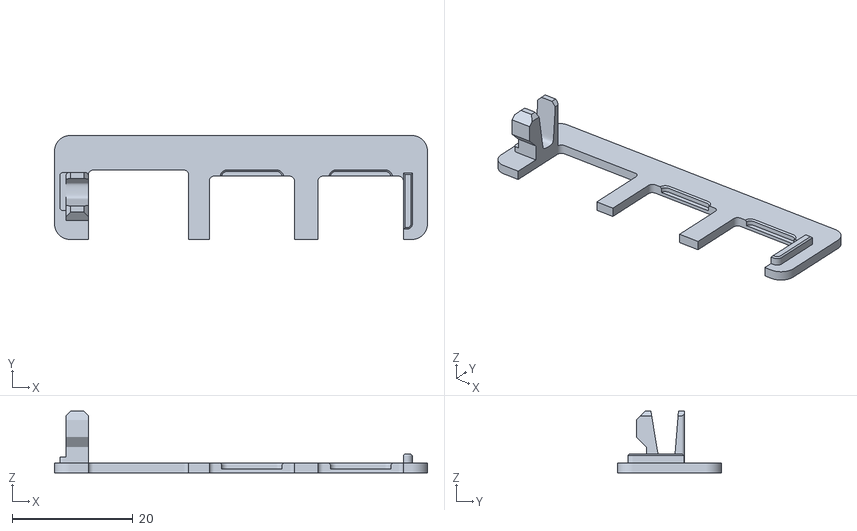
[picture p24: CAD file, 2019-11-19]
Documentation/Case Files/CAP.STL
61.7 x 17.2 x 10.2

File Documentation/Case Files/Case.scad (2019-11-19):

difference(){
    union(){
        rotate([90,0,0])import("C:/Users/n01158072/Downloads/MAIN (1).STL");
        $fn=64;
        translate([31,-18.3,17.2]){

        xdim2 = 57;
        ydim2 = 37;
        zdim2 = 1;
        translate([-xdim2/2, -ydim2/2, -zdim2])
        {
            cube([xdim2,ydim2,zdim2]);
        }
    }
    }
    xdim1 = 56;
    ydim1 = 35;
    zdim1 = 90;
    translate([31,-18.3,17.2]){
        translate([-xdim1/2, -ydim1/2, -11.5])
        {
            cube([xdim1,ydim1,zdim1]);
        }
    }
}
translate([0,10,0]){
import("C:/Users/n01158072/Downloads/CAP.STL");
}

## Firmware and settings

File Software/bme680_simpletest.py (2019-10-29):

import time
import board
from busio import I2C
import adafruit_bme680

# Create library object using our Bus I2C port
i2c = I2C(board.SCL, board.SDA)
bme680 = adafruit_bme680.Adafruit_BME680_I2C(i2c, debug=False)

# change this to match the location's pressure (hPa) at sea level
bme680.sea_level_pressure = 1013.25

while True:
    print("\nTemperature: %0.1f C" % bme680.temperature)
    print("Gas: %d ohm" % bme680.gas)
    print("Humidity: %0.1f %%" % bme680.humidity)
    print("Pressure: %0.3f hPa" % bme680.pressure)
    print("Altitude = %0.2f meters" % bme680.altitude)

    time.sleep(1)
